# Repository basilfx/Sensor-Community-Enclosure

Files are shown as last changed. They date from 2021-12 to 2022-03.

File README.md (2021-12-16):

# Sensor Community Enclosure
3D printed version of a Sensor.Community Air Sensor enclosure.

## Introduction
This repository contains the parts and assembly instructions for creating my
version of the [Sensor.Community](https://sensor.community/en/sensors/airrohr/)
Air Sensor. This sensor uses a relativly cheap PM2.5/PM10 sensor, to measure
the air quality. This data is then shared with
[Sensor.Community](https://maps.sensor.community/) and other instances, to
keep track of the (local) air quality.

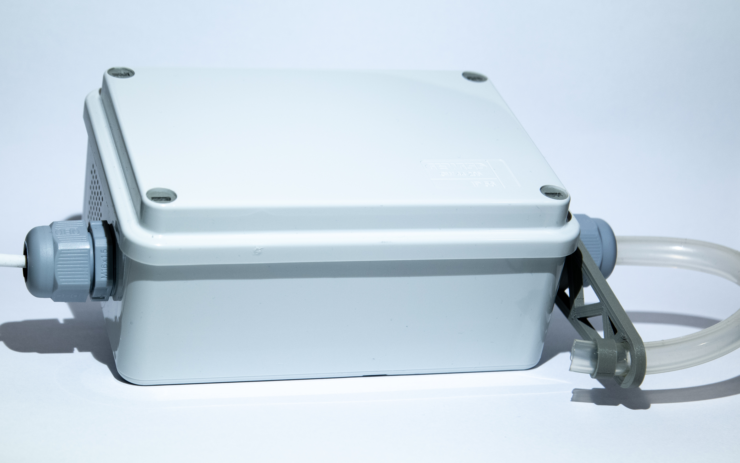
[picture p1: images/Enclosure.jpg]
Sensor enclosure overview.
[](images/Enclosure.jpg)
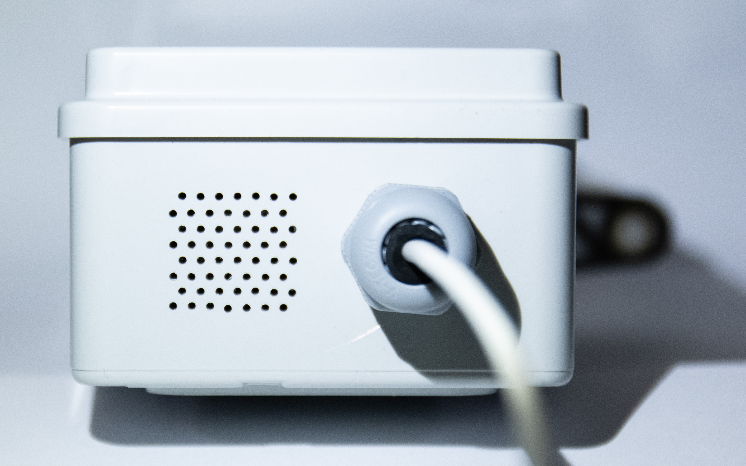
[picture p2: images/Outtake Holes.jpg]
Sensor outtake holes.
[](images/Outtake%20Holes.jpg)
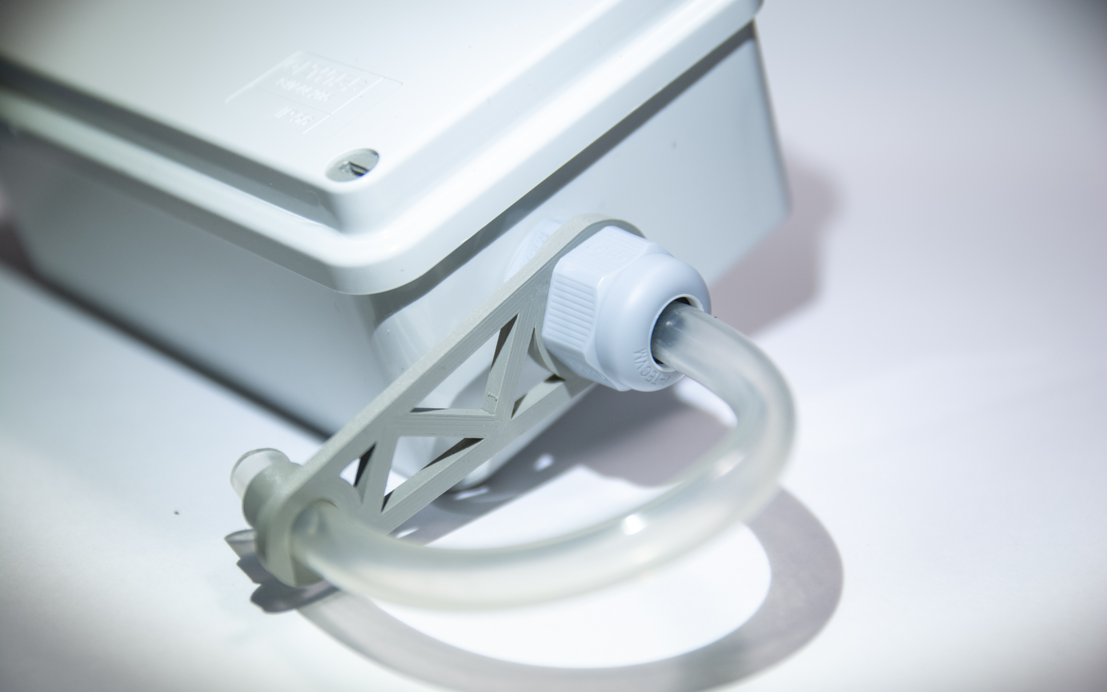
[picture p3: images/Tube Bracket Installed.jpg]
Sensor intake bracket.
[](images/Tube%Bracked%Installed.jpg)
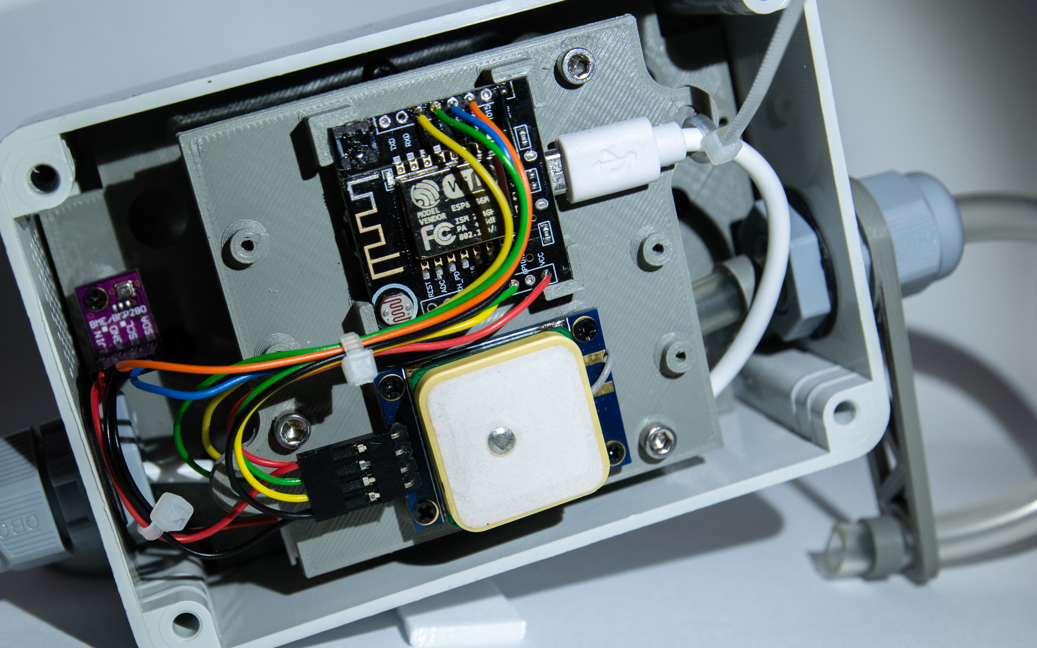
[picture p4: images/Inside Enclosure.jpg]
Inside the sensor.
[](images/Inside%20Enclosure.jpg)

## Features
* 3D printed parts (for the specific enclosure I used, +/- 80x120 mm)
* Rigid mounting with additional weatherproofing
* Air quality, temperature and GPS (location and altitude)

## Contents
* The `3d/` folder contains a 3D-printable designs for the necessary parts.
* The `firmware/` folder contains a compiled version of the Airrohr firmware I
  used (added for archiving reasons).
* The `images/` folder contains several pictures of the assembled sensor.

## Instructions
Printing, assembly and flashing instructions can be found in
[Instructions.md](Instructions.md).

## License
The work in this repository is covered by CC BY-NC-SA 4.0. See the `LICENSE.md`
file for more information.

Some parts of this project are covered by a different license.

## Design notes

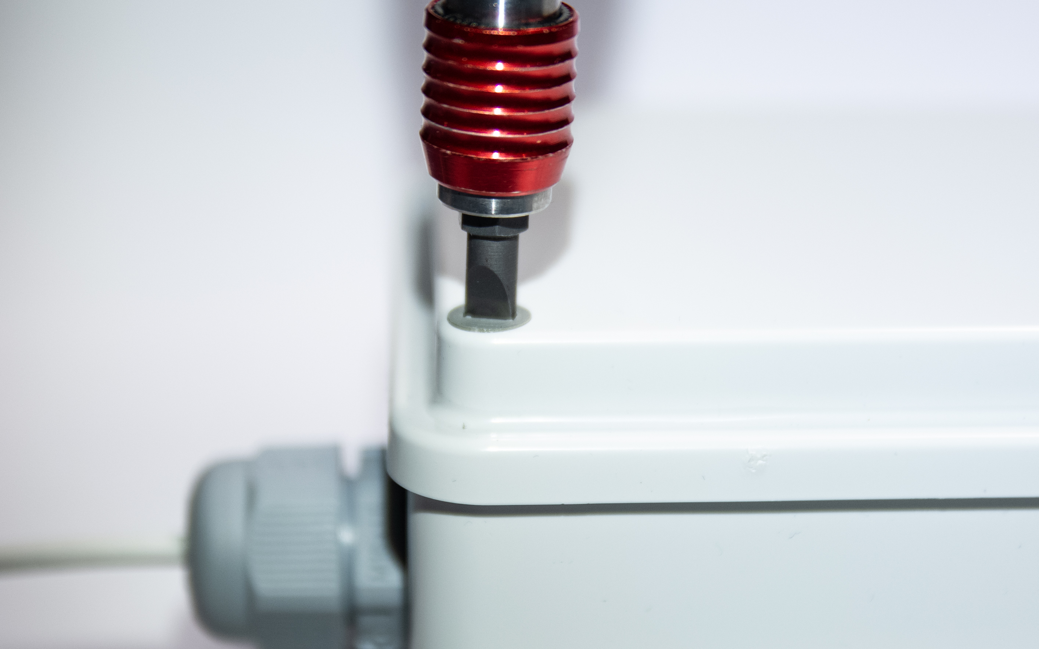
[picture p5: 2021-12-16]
images/Opening enclosure.jpg

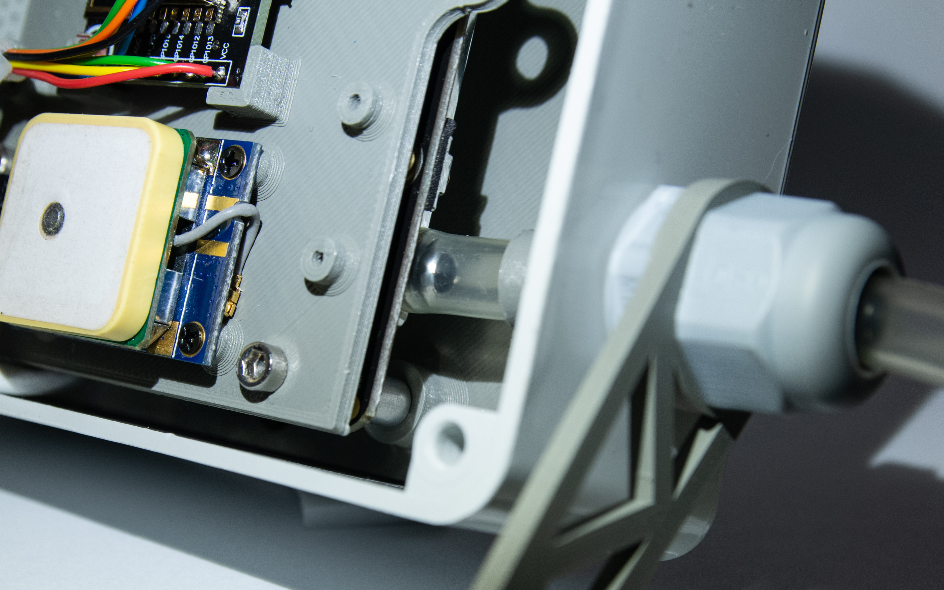
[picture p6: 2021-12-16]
images/Intake.jpg

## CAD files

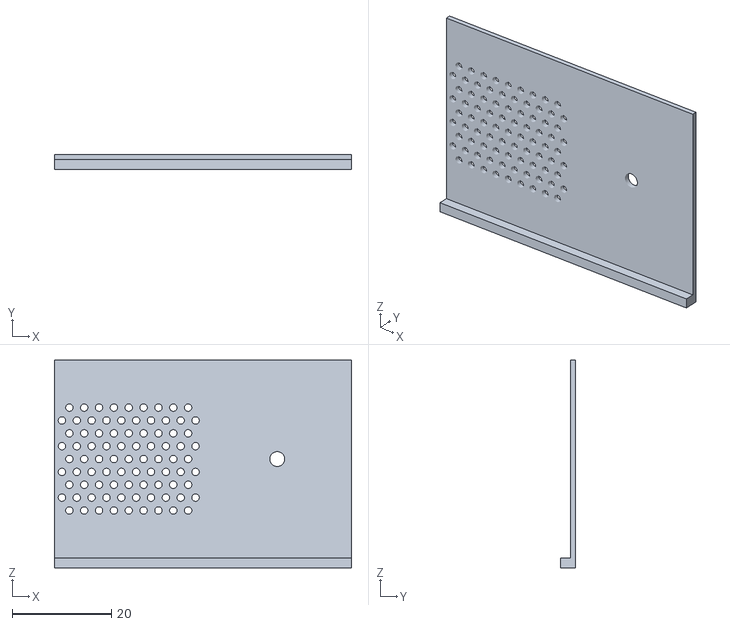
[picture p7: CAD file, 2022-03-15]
3d/enclosure/Drill Template - Bottom.stl
60.0 x 3.00 x 42.0

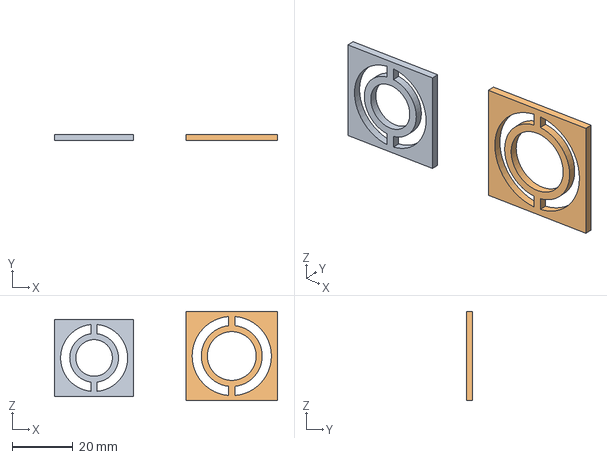
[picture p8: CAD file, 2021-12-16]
3d/other/Rubber Seal Template.step
73.2 x 2.00 x 29.4 mm

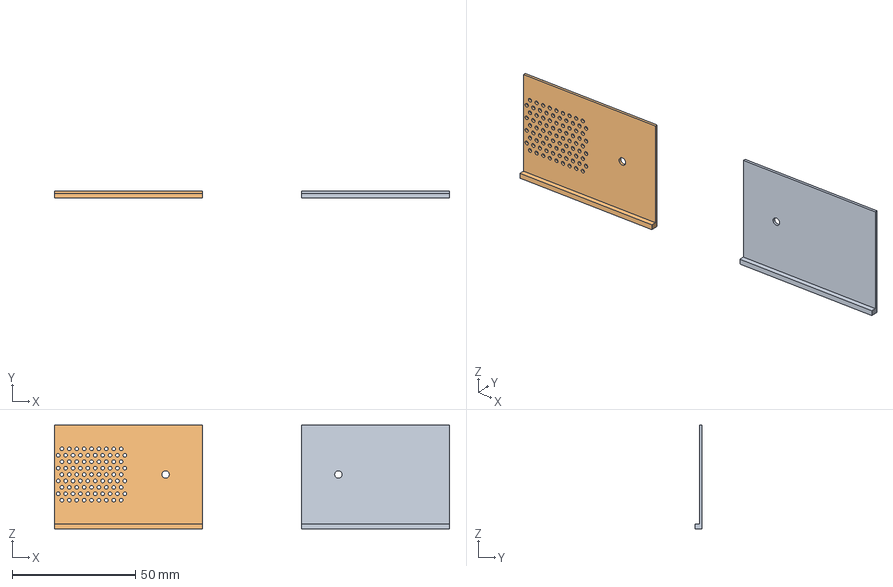
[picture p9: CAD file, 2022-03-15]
3d/enclosure/Drill Template.step
160.0 x 3.00 x 42.0 mm

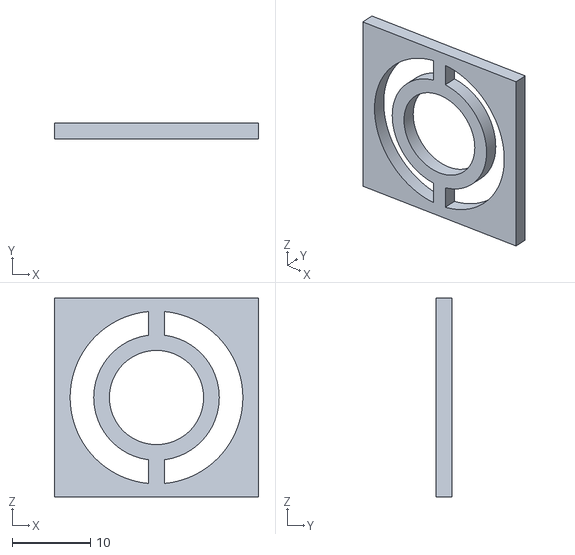
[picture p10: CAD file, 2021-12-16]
3d/other/Rubber Seal Template - 12mm.stl
26.0 x 2.00 x 25.3

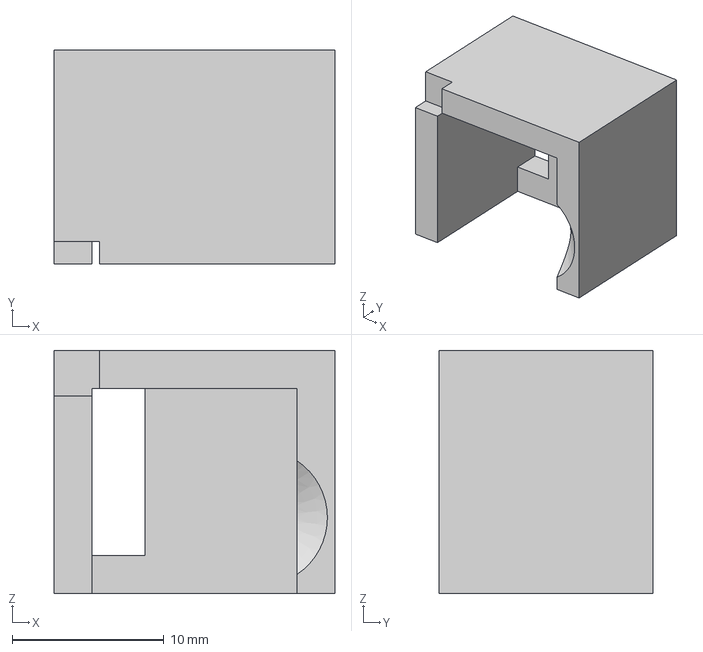
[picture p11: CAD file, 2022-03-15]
3d/enclosure/Temperature Sensor Cover.step
18.5 x 14.1 x 16.0 mm

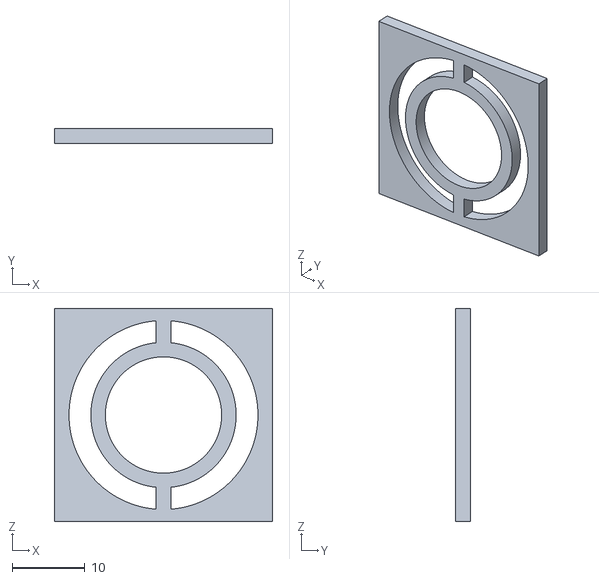
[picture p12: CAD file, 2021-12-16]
3d/other/Rubber Seal Template - 16mm.stl
30.0 x 2.00 x 29.4

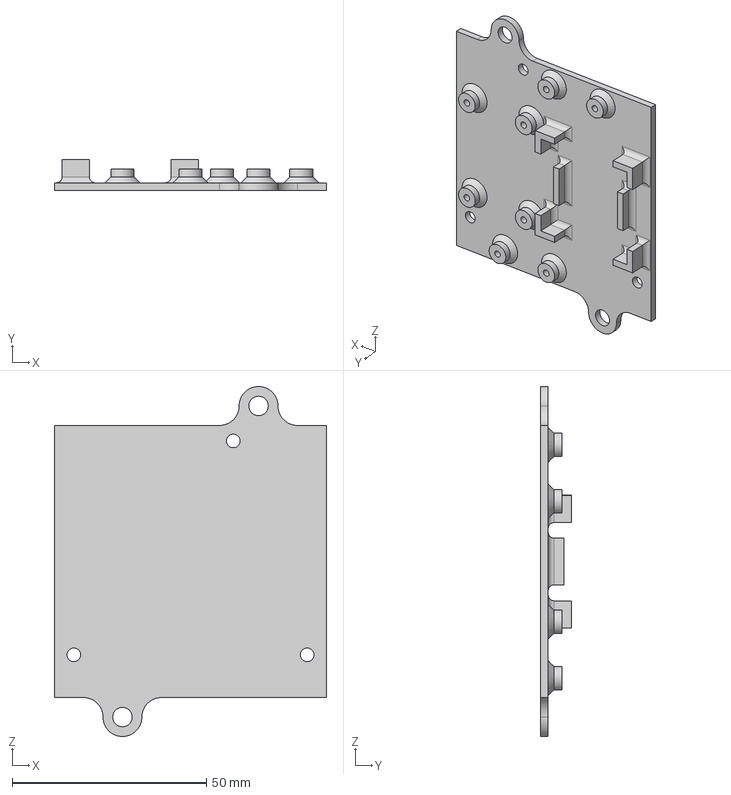
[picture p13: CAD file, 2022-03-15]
3d/enclosure/PCB Bracket - Witty Board.step
70.0 x 8.00 x 90.0 mm

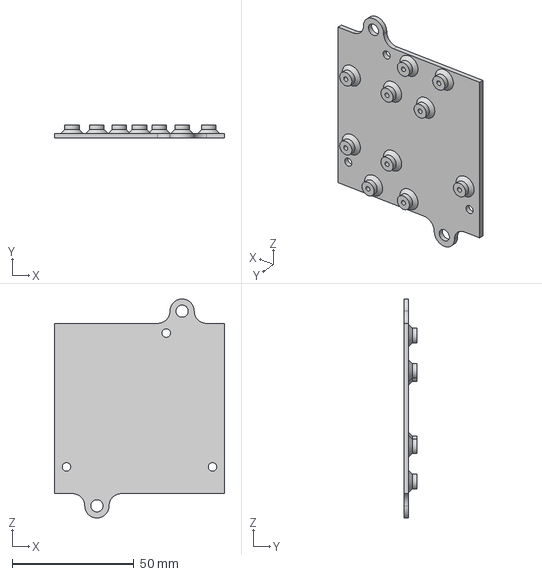
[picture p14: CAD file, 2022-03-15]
3d/enclosure/PCB bracket - Wemos D1 Mini V3.step
70.0 x 5.50 x 90.0 mm

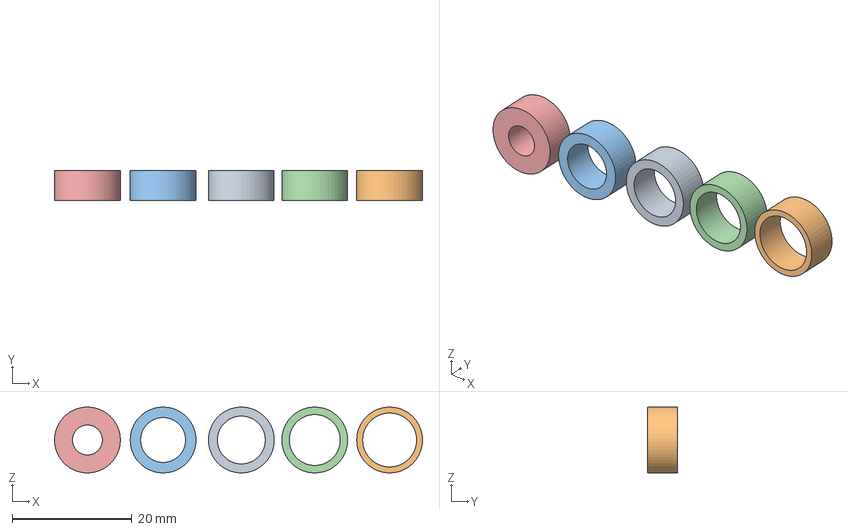
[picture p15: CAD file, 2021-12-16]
3d/enclosure/Tube Rings.step
61.4 x 5.00 x 11.0 mm

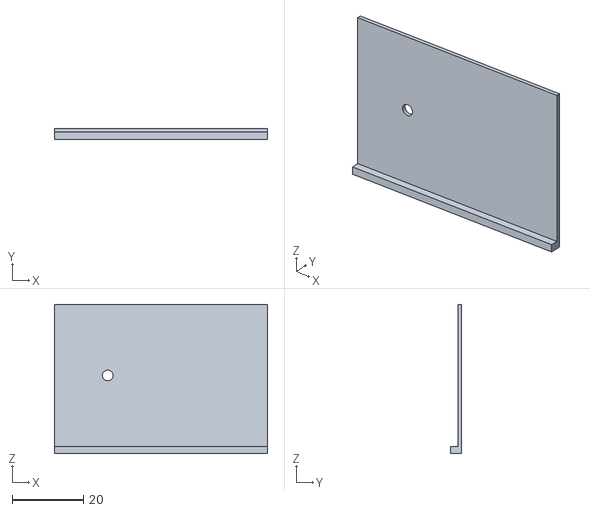
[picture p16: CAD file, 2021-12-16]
3d/enclosure/Drill Template - Top.stl
60.0 x 3.00 x 42.0

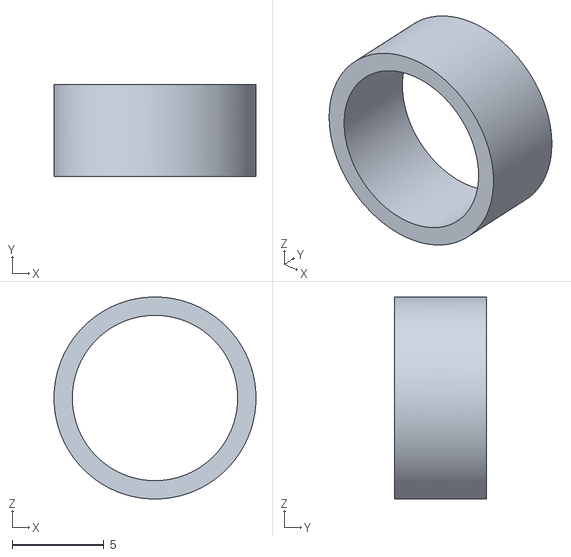
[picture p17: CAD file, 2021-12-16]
3d/enclosure/Tube Ring - 8mm.stl
11.0 x 5.00 x 11.0

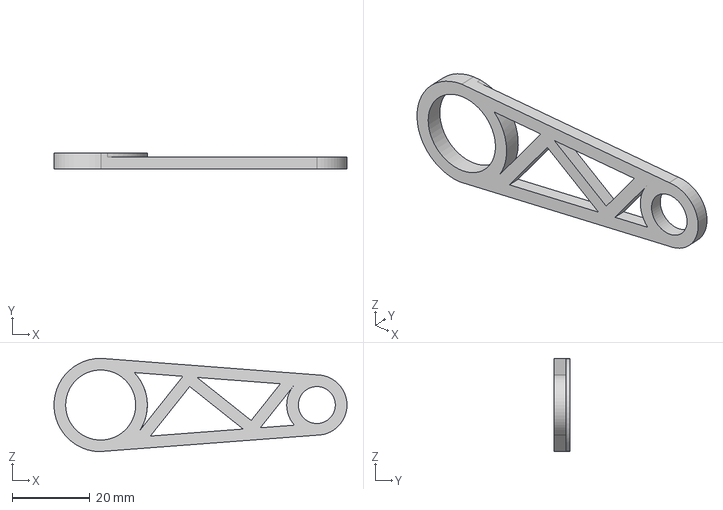
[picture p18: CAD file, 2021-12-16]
3d/enclosure/Tube Bracket.step
75.3 x 4.00 x 24.0 mm

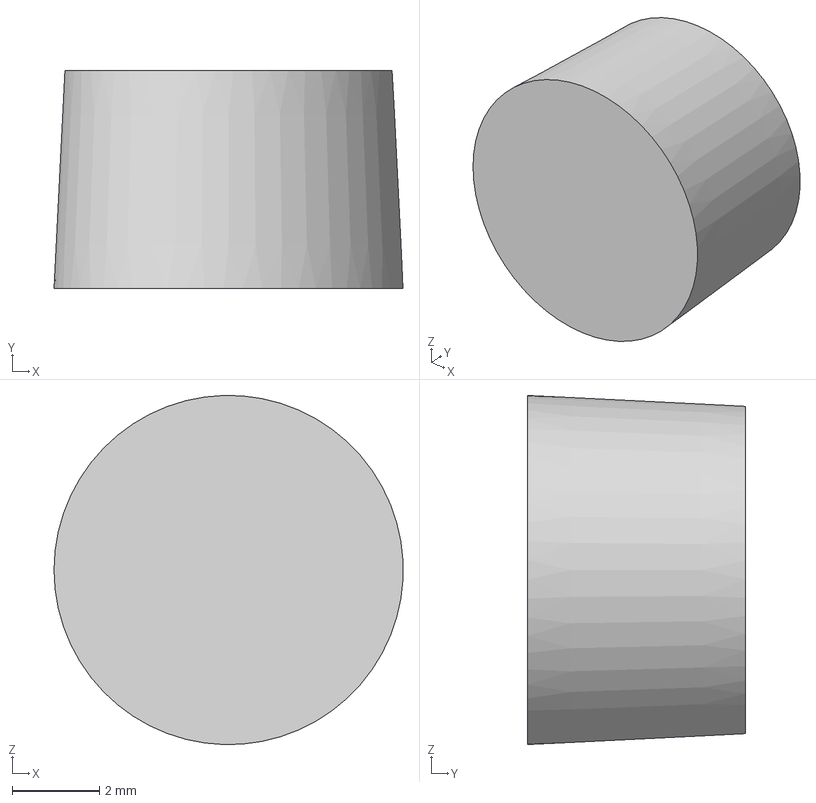
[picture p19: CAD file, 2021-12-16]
3d/enclosure/Screw Hole Cover.step
7.99 x 5.00 x 8.00 mm

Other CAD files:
3d/enclosure/Enclosure Bracket.step
3d/enclosure/Enclosure Bracket.stl
3d/enclosure/PCB bracket - Wemos D1 Mini V3.stl
3d/enclosure/PCB bracket - Witty Board.stl
3d/enclosure/Screw Hole Cover.stl
3d/enclosure/Temperature Sensor Cover.stl
3d/enclosure/Tube Bracket.stl

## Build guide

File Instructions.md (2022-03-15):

# Instructions

* [Introduction](#introduction)
* [Printing the parts](#printing-the-parts)
* [Assembly](#assembly)
  + [Creating the cable loom](#creating-the-cable-loom)
  + [Drilling the enclosure holes](#drilling-the-enclosure-holes)
  + [Installing the enclosure bracket](#installing-the-enclosure-bracket)
  + [Installing the cable glands](#installing-the-cable-glands)
  + [Installing the electronics](#installing-the-electronics)
  + [Hooking it up](#hooking-it-up)
    - [Flexible tube length](#flexible-tube-length)
  + [Finishing steps](#finishing-steps)
* [Flashing the firmware](#flashing-the-firmware)
* [Configuration](#configuration)
  + [Advanced configuration](#advanced-configuration)
    - [Temperature correction](#temperature-correction)
    - [GPS configuration](#gps-configuration)
* [Registration](#registration)
* [Home Assistant integration](#home-assistant-integration)
  + [Local Luftdaten](#local-luftdaten)
* [Mounting instructions](#mounting-instructions)
* [Troubleshooting](#troubleshooting)

## Introduction
The steps in these introductions are all the steps I needed to create a single
enclosure. Feel free to adapt, replace or skip any of the steps, to make your
own version.

Some of the photos in this guide are from a prototype version using the
Witty Board. While this might look different, all of the steps are quite
similar.

## Printing the parts
You can find the printable files in the [3d](3d/) folder. The parts do not
require special attention. Make sure that you print the parts with the biggest
flat surface down. At least 20% infill will ensure they are rigid enough. I
used PLA, but since the sensor must not be installed in direct sunlight, I do
not expect any problems.

It depends on the use-case if you need all the parts.

You need at least:

* Enclosure bracket
* PCB bracket
* Screw hole covers
* Temperature sensor cover

For usage with a flexible tube:

* Tube bracket
* Tube fixing ring (2x)

For easy drilling of the enclosure:

* Drill templates (top and bottom)
* Rubber seal templates (16 mm and/or 12 mm)

You might need to adapt the tube fixing rings to your particular tube. There
might be slight differences in the flexible tube outer diameter. The rings must
fit tightly, so they stay in place.

## Assembly

### Creating the cable loom

For this step, you will need:

* 4-pin 2.54 mm male header
* 4-pin 2.54 mm male header right angled
* 4-pin 2.54 mm female Dupont headers (2x) with terminal pins (8x)
* JST terminal pins (4x)
* Wires (thin, six colors if possible)
* Pliers, crimping tools and wire strippers

Optionally, if you plan to connect to the power line directly:

* 2-pin 2.54 mm female Dupont header with terminal pins (2x)
* 2-pin 2.54 mm male Dupont header with terminal pins (2x, for contra cable)

The sensors can be soldered to the ESP8266, but another option is to create a
cable loom and use wire-to-board connectors.

The cable should be assembled as follows (do not solder it to the ESP8266 yet):

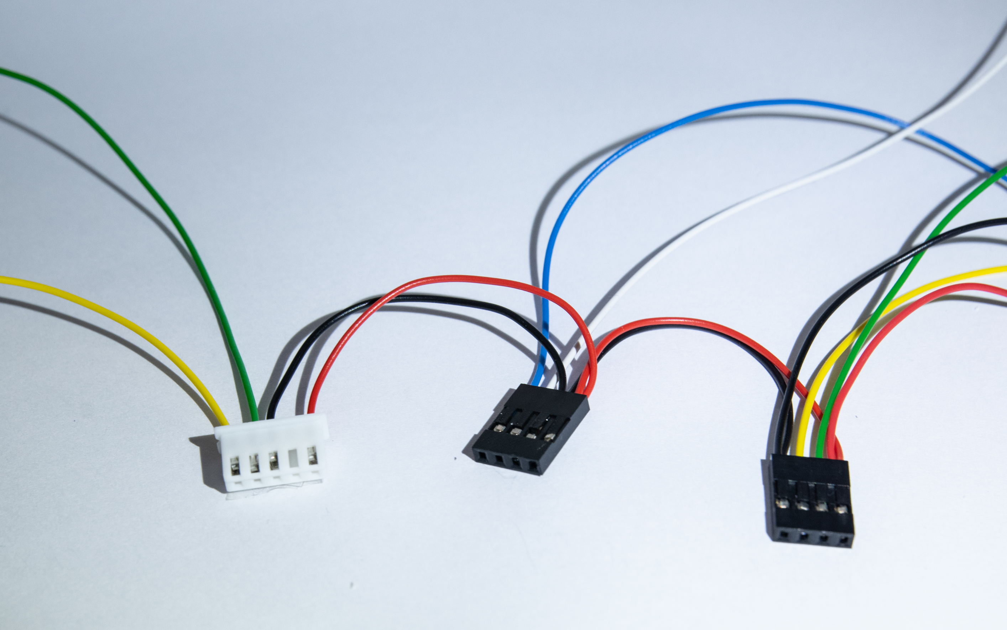
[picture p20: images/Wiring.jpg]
The actual wiring loom.
[](images/Wiring.jpg)
[Overview of the wiring loom.](images/Wiring%20Overview.svg)

You can re-use the JST connector housing that comes with the SDS011 cable.

### Drilling the enclosure holes
For this step, you will need:

* Enclosure (Gewiss GW44 205)
* A slow (hand-operated) drill with a 1 - 1.4 mm drill bit
* An electric drill with a 3 mm drill bit
* A 16 mm spade drill bit
* Small piece of scrap wood
* Strong adhesive tape
* Sharp chisel or another deburring tool

The drilling step is a time-consuming step.

Secure the drill templates on the top and bottom side of the enclosure, using
some strong adhesive tape. The templates should be centered and tightly mounted
to the edge of the enclosure.

The small holes should be drilled carefully. Use a hand-operated drill, because
an electric drill will melt the plastic, clogging up the drill and potentially
breaking the drill itself.

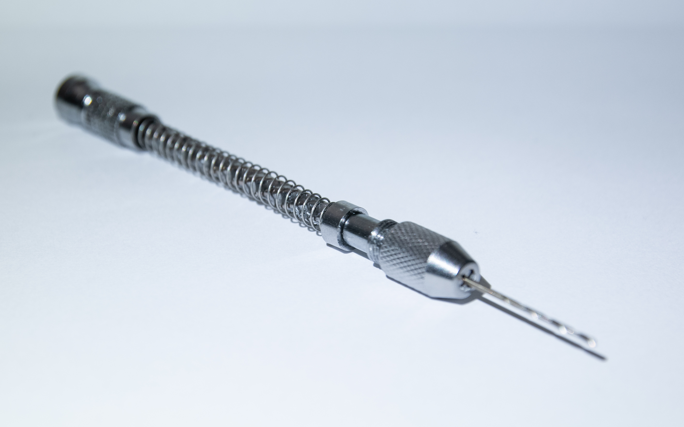
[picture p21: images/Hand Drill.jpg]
A hand drill
[](images/Hand%20Drill.jpg)
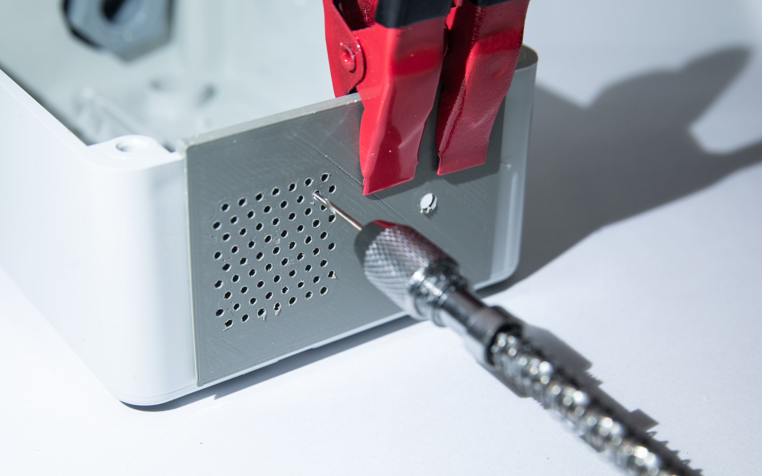
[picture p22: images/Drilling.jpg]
Drilling in of the outtake holes.
[](images/Drilling.jpg)

The bigger holes should be pre-drilled using a 3 mm drill bit first. Use a
piece of scrap wood on the back side, so that the drill bit does not shoot
through the plastic, potentially damaging the enclosure.

On the bottom side (next to the outtake holes), use the 16 mm spade drill bit
to create a hole for the cable gland for the power supply. On the top side, use
a 16 mm spade drill bit for the flexible tube as well. Use the piece of scrap
wood on the back side of the plastic.

**Note:** make sure that you hold the enclosure firmly during drilling. If the
spade drill bit gets stuck, it might start to rotate the enclosure.

**Note:** if you plan to directly solder the power supply cable, you can better
drill a 12 mm hole on the bottom side.

Clean-up all the holes and remove any of the burrs. This ensures that the
rubber seals can be mounted properly. A chisel works great in this case,
without scratching the plastic.

### Installing the enclosure bracket
For this step, you will need:

* Enclosure bracket
* M3 Brass inserts (5.3 mm outer diameter, 5 mm or 6 mm tall)
* M3 8 mm self-tapping button-head screws (4x)
* An electric drill with a 3 - 4 mm drill bit
* Small piece of scrap wood
* Soldering iron

Drill the enclosure mounting holes first, depending on your desires. If you
decide to hang it on two scows, make sure that you drill the two top holes
only. Use the scrap piece of wood to ensure that the drill bit does not shoot
through the case.

Insert the M3 brass inserts in the three bigger stand-offs on the enclosure
bracket. The easiest is to do this with a soldering iron. Make sure that the
molten plastic does not get inside the brass insert. One way to do so, is to
insert a small M3 bolt first (e.g. 5 mm or 6 mm bolt). If you struggle to get
the M3 brass inserts flush due to the molten plastic, you can decide to drill
the holes first, so that the molten plastic can get out.

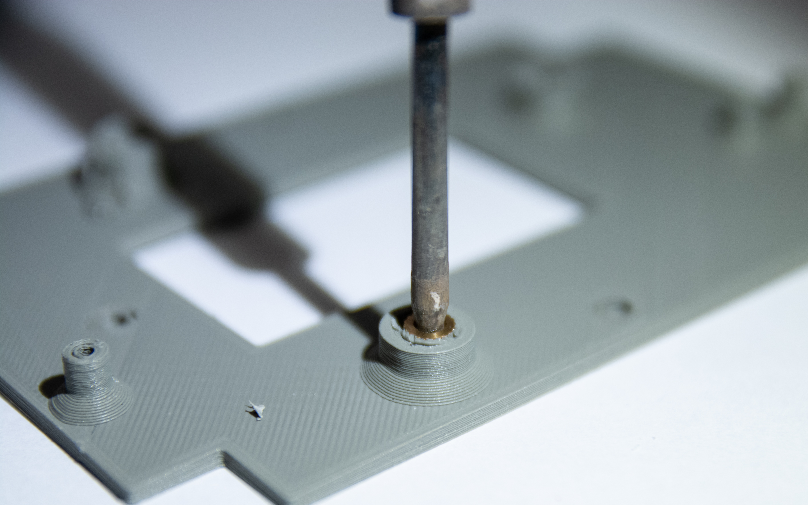
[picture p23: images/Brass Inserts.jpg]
Sensor outtake holes.
[](images/Brass%20Inserts.jpg)

Mount the enclosure bracket next. Use the four M3 self-tapping screws to secure
it to the enclosure.

### Installing the cable glands
For this step, you will need:

* Cable gland 16 mm (2x) including nut (2x)
* Rubber seal 16 mm (2x)

**Note:** you can also cut some seals from an old bicycle tire, using the
rubber steal template.

Install the cable glands on the top and bottom side. From the inside, put on
the rubber seal first and then the nut. Tighten the nut by hand, ensuring that
it is as tight as possible. Verify that it will not come loose when you tighten
the cable gland itself.

The rubber seal ensures that the cable gland does not get loose and prevents
water from coming in.

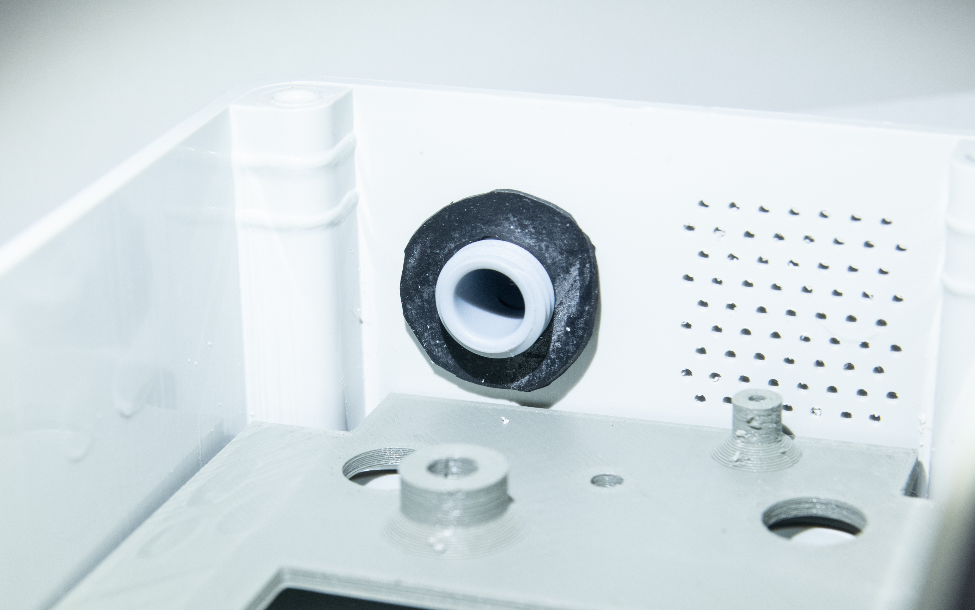
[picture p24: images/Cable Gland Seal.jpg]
Cable gland with seal.
[](images/Cable%20Gland%20Seal.jpg)
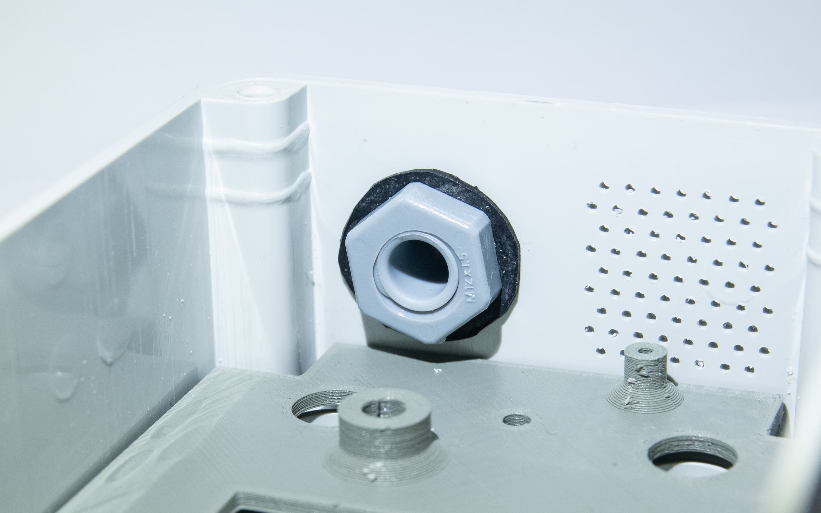
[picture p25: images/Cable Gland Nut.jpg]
Cable gland with seal and nut.
[](images/Cable%20Gland%20Nut.jpg)

If you decide to mount the enclosure, now is the time to mount it to its final
destination. The enclosure mounting screws will be hard to reach once you
finish the next step. To improve water resistance, use a M3 or M4 seal on the
inside between the screw and the enclosure.

### Installing the electronics
For this step, you will need:

* M3 15 mm brass stand-offs with 6 mm thread (3x)
* M3 spacer 3 mm (3x)
* M3 10 mm bolt
* ESP8266 (Wemos D1 Mini V3)
* Air quality sensor (SDS011)
* GPS sensor (NEO-6M, NEO-7M or NEO-M8N with the blue PCB and solderable
  antenna).
* Temperature and humidity sensor (BME-280, 5 V version)
* PCB bracket
* M2 self-taping screws
* Wiring loom, or wires for soldering
* Temperature sensor cover
* Hot glue

Fix the GPS sensor and the ESP8266 on the PCB bracket.

Install the brass stand-offs in the brass inserts in the enclosure bracket.
Then place the air quality sensor on top, with the fan down. Then place the
PCB bracket on top, using 3 mm spacers. Fix them with the 10 mm M3 bolts.

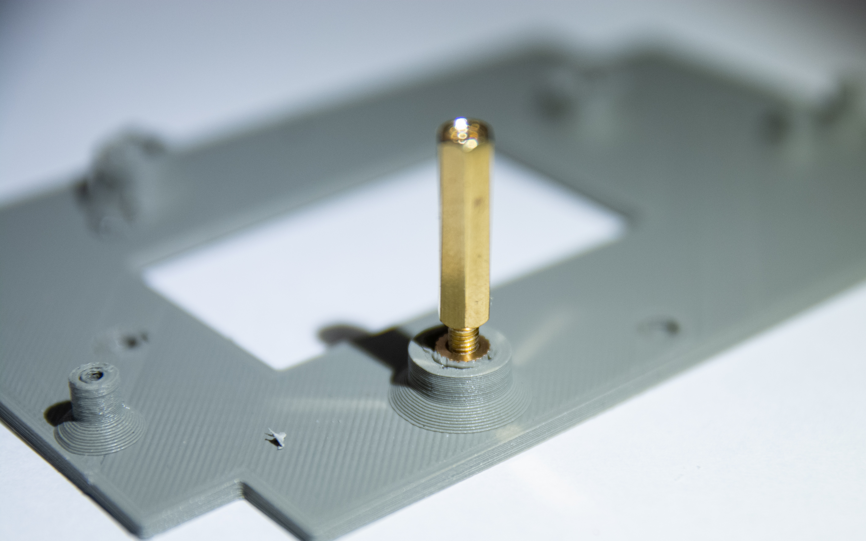
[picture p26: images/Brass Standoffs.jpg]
Installation of the brass standoffs.
[](images/Brass%20Standoffs.jpg)

The BME-280 temperature sensor can be mounted next to the outtake holes, using
a small screw. It is recommended to mount the temperature sensor cover as well,
to isolate the temperature sensor better from the inside air. A drop of hot
glue should keep it in place. I must admit that this sensor cover is an
afterthought, to make the temperature readings more accurate.

Finally, connect the wiring loom in accordance with the wiring diagram above.
Use the following pinout:

SDS011:

* Pin 1 (TX) -> Pin D1 (GPIO5)
* Pin 2 (RX) -> Pin D2 (GPIO4)
* Pin 3 (GND) -> GND
* Pin 4 (2.5m) -> unused
* Pin 5 (5 V) -> 5 V
* Pin 6 (1m) -> unused

BME-280 (5 V version):

* Pin 1 (VCC) -> 5 V
* Pin 2 (GND) -> GND
* Pin 3 (SCL) -> Pin D4 (GPIO2)
* Pin 4 (SDA) -> Pin D3 (GPIO0)

NEO-6M, NEO-7M or NEO-M8N:

* Pin 1 (VCC) -> 5 V
* Pin 2 (TX) -> Pin D5 (RX)
* Pin 3 (RX) -> Pin D6 (TX)
* Pin 4 (GND) -> GND

[Inside an assembled enclosure.](images/Inside%20Enclosure.jpg)

### Hooking it up
For this step, you will need:

* Tube fixing ring (2x)
* Tube bracket
* 15-20 cm flexible tube (6 mm inner diameter, 8 mm outer diameter)
* Power supply cable (e.g. USB cable)
* Zip tie

Insert the flexible tube through the cable gland and connect it to the intake
of the air sensor. Install a tube fixing ring on the inside. This ring should
prevent water (if any at all) from running down the tube into the sensor.
Then install the tube bracket on the cable gland and install the flexible tube
to the bracket, with a tube fixing ring on the end.

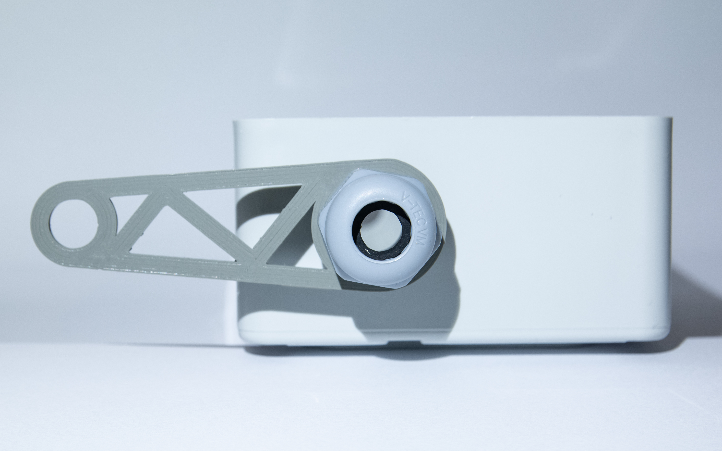
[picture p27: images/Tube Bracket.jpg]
Tube bracket without tube.
[](images/Tube%20Bracket.jpg)
[Tube bracket installed.](images/Tube%20Bracket%Installed.jpg)

Install the power supply cable. The USB cable should fit thourgh the 16 mm
cable gland. Route it behind the PCB bracket and connect it to the ESP8266. Use
zip tie to fix it to the PCB bracket top hole, for additional stress
relief.

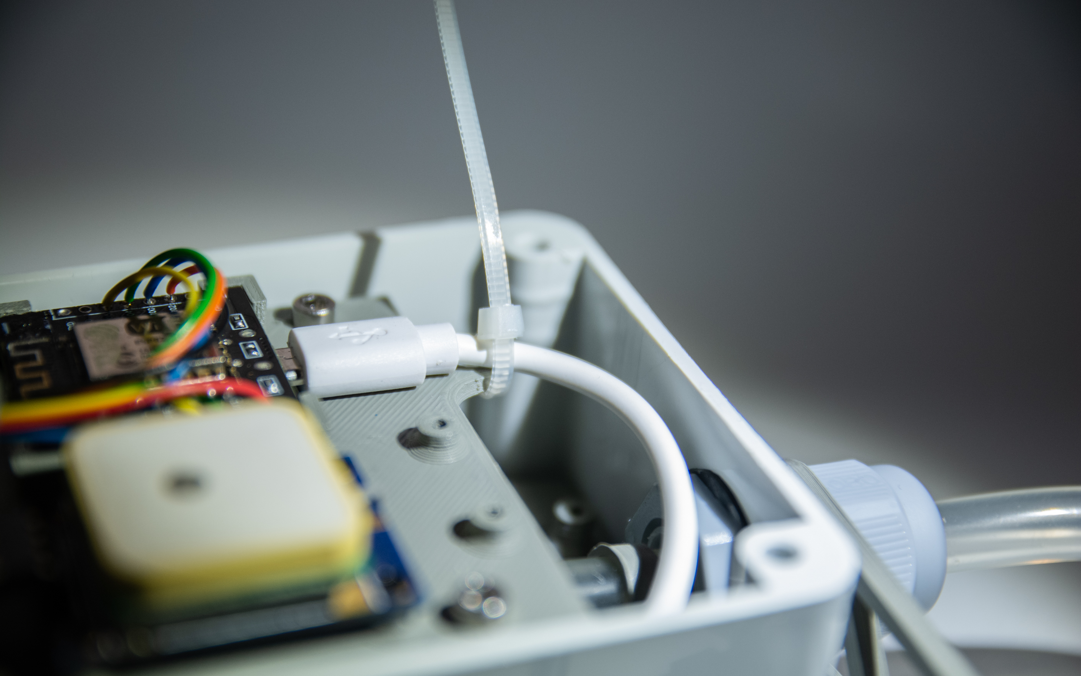
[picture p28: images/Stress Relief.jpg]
Zip tie for stress relief.
[](images/Stress%20Relief.jpg)

The cable gland on the bottom should be tightened all the way for the power
supply cable. This acts as an additional strain relief. The cable gland one on
top should be tightened as well, but not too tight. The flexible tube must not
be compressed too much otherwise it could obstruct the air flow. Make sure that
if you pull on the tube, it cannot move. Then look down the tube, to see if you
do not see any inward affliction of the tube.

#### Flexible tube length
The shorter the tube, the better it is. According to the datasheet of the
sensor, a tube length up to 1 m is allowed. The original manual suggests the
use of a 20 cm tube. The Dutch National Institute for Public Health and the
Environment, who are [stimulating] people to join the Sensor.Community,
suggests to use a tube less than 5 cm, to increase plausibility of
measurements.

For my design, a tube of approximately 15-20 cm is necessary to create an
unobstructed 180 degree bend. Without a tube, it would be hard to ensure that
the sensor is mounted upright AND make it water-resistant. It also ensures that
the sensor sucks up fresh air (away from the outtake). You can decrease the
tube length if you mount the sensor on a dry location (even removing the tube
bracket at all).

The tube has a inner diameter of 6 mm (~28 mm² of area), the actual intake
port has a diameter of 5 mm (~19 mm² of area). The 85 outtake holes (~96 mm²
of area) should allow for an unobstructed air flow. I have compared my sensor
with other nearby sensors, and it performs identical.

A more-scientific study observed a decrease in the maximum air flow of the
flexible tube, with longer tube lengths. Comparing 20 cm with 100 cm, the air
flow decreased linearly from 664 ml/min to 412 ml/min. Every 1 cm of tube would
impact the maximum air flow by about 0.5 %. Note that this is the maximum air
flow, which may be much higher than the air flow generated by the air quality
sensor. More details of this research can be found
[here](https://pudi.lubw.de/detailseite/-/publication/90536).

### Finishing steps
For this step, you will need:

* The screw hole covers (4x)
* M3 x 7 mm rubber seals (4x)

Last step is to install the lid. The enclosure comes with four screws to close
the lid. For additional water proofing, add a M3 rubber seal and finish it off
with a screw hole cover.

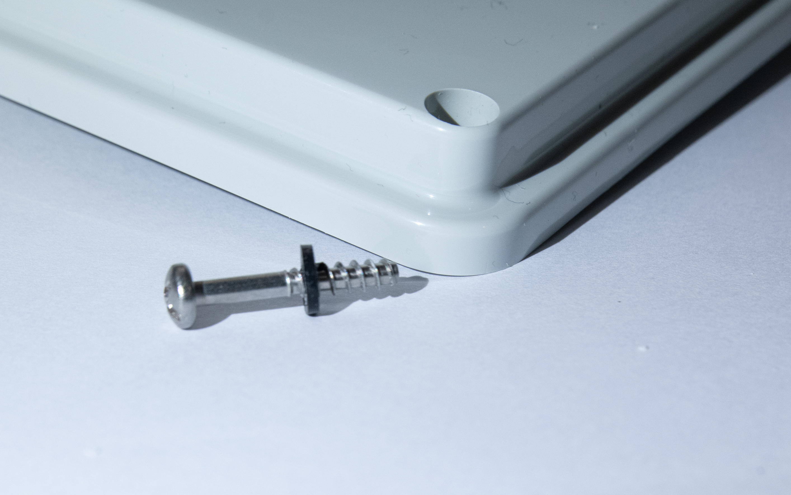
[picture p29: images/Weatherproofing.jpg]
Weatherproofing of the screws.
[](images/Weatherproofing.jpg)

The screw hole cover can be removed with a large flat head.

Your sensor is now ready for use.

## Flashing the firmware
For this step, you will need:

* A micro USB cable
* [esptool.py](https://github.com/espressif/esptool)
* Firmware file (see [firmware](firmware/) folder.

From the command line, invoke:

```
esptool.py --port [PORT] write_flash -fm dio 0x00000 latest_en.bin
```

Replace `[PORT]` with the serial port of your sensor. It is typically
`/dev/tty/tty.USBxyz` on Linux and `COMn` on Windows.

Once flashing is completed, power cycle the sensor.

## Configuration
Power-on the sensor. If it has not been configured before, it will start a
wireless network. Connect to this network, and navigate to http://192.168.4.1.

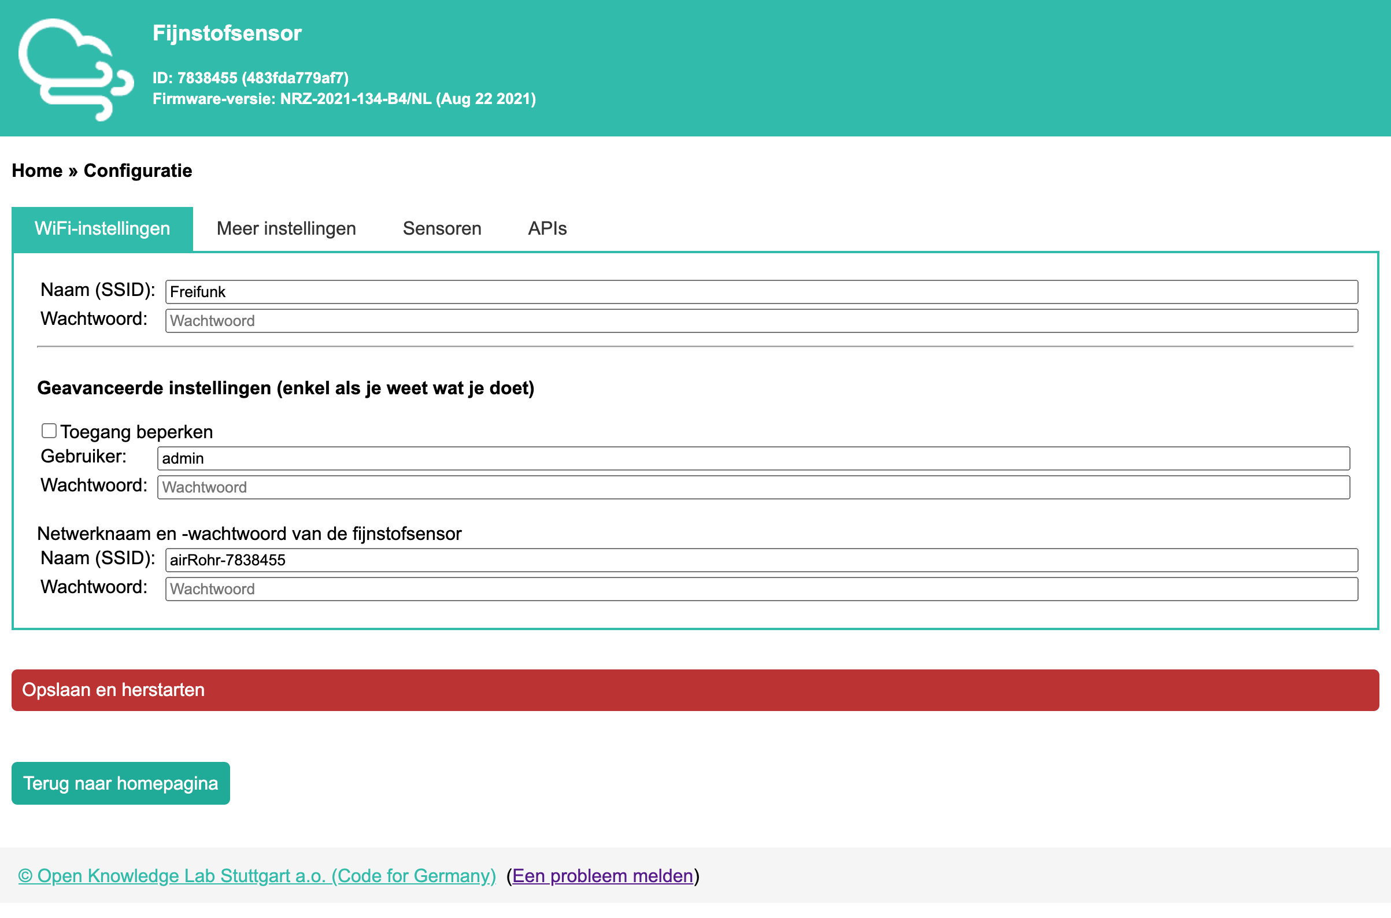
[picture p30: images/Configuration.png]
Configuration screen (Dutch firmware).
[](images/Configuration.png)

On the configuration page, you can configure the WiFi network to use. It is
also possible to configure the hardware and API connections. Some points of
attention:

* Make a note of the 7-digit identifier shown in the top bar. You will need
  this in the next step.
* Enable beta updates. Note that your sensor may seem unresponsive the next
  time it boots, because it will most likely download the new firmware.
* Enable the Sensor.Community API integration (using HTTPS). Enable others as
  desired. You do not need to enable any API integrations if you decide to use
  the local Home Assistant integration.
* Ensure that you enable the right hardware. For this build, enable
  * SDS011
  * BME280
  * GPS (NEO-6M, NEO-7M or NEO-M8N)

If the sensor cannot find the configured wireless network, it will start its
own wireless network again. You can then start over.

### Advanced configuration
The WiFi chip and the GPS chip are power-hungry. This results in some
heating-up of the enclosure, depending on the exact module used and the amount
of WiFi traffic. This will affect the BME280 temperature and humidity readings.

#### Temperature correction
It is possible to account for an offset of the temperature readings in the
firmware (this is not possible for humidity, unfortunately). To find the
offset, it is possible to run the sensor for some time, without the lid of the
enclosure mounted. The graphs below show the offsets for two of my sensors
(yellow line is the one without the lid mounted).

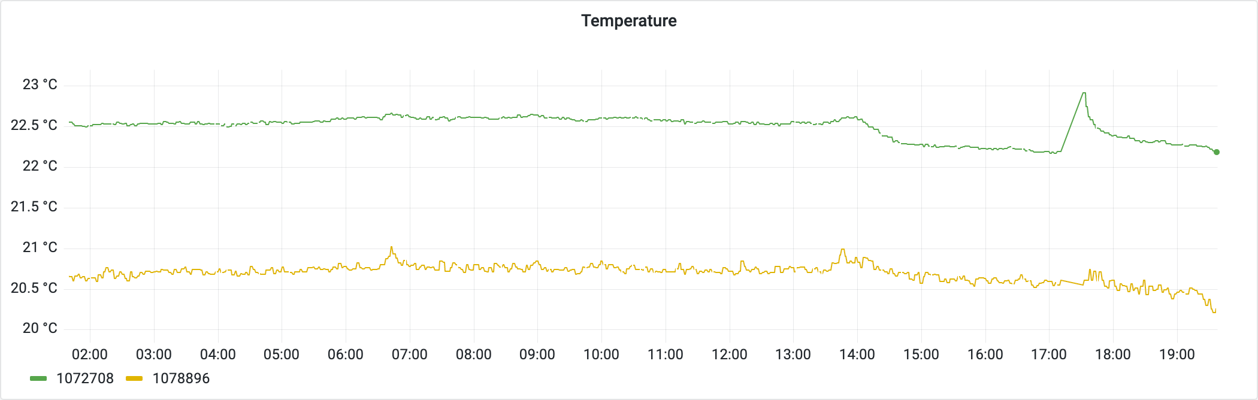
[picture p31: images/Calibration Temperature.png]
Temperature offset with and without lid.
[](images/Calibration%20Temperature.png)
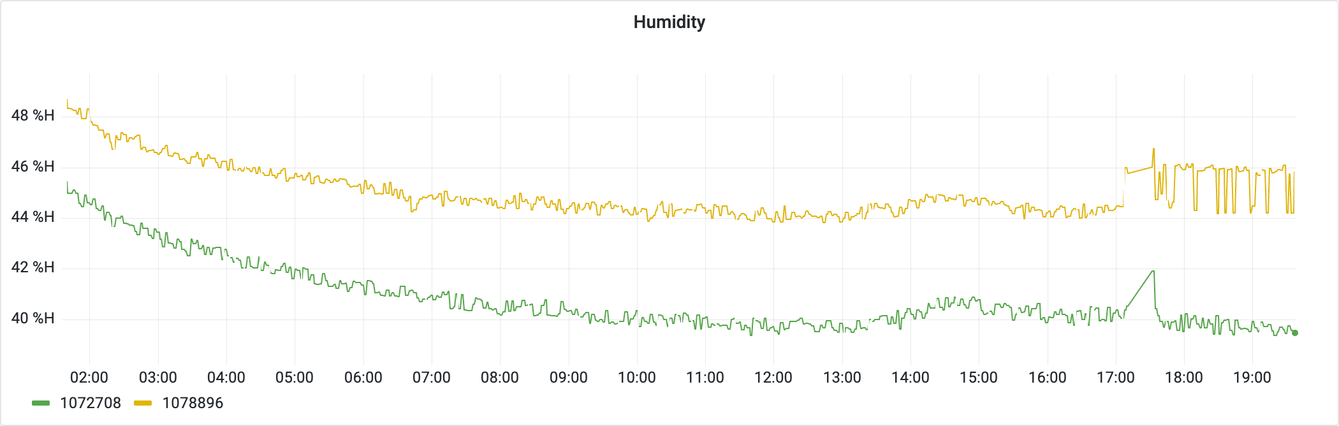
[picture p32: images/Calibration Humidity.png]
Humidity offset with and without lid.
[](images/Calibration%20Humidity.png)

The graph show an offset of about 1 °C to 2 °C, and it follows the temperature
curve of the enclosure without the lid. Similar results were achieved in
different environments.

#### GPS configuration
The NEO-M8N is more-efficient than the NEO-6M or NEO-7M. Using the u-blox
configuration tool, it is possible to enable more-efficient power saving modes,
at the expense of accuracy (which isn't a problem for a stationary device). Do
note that that not all devices have built-in flash for storing configuration
parameters, so they might be erased after power cycling. Consult the following
sources for more information:

* https://www.u-blox.com/sites/default/files/products/documents/u6-PowerMgt_AppNote_%28GPS.G6-X-10014%29.pdf
* https://www.u-blox.com/sites/default/files/products/documents/PowerManagement_AppNote_%28UBX-13005162%29.pdf

## Registration
If you decide to contribute to Sensor.Community, you can go to
https://devices.sensor.community/ to create an account.

Once you have created an account, you can add sensors using the sensor
identifier from the previous step. An important note here is that you cannot
modify an existing sensor, and if you delete it, you cannot register it again.
Make sure that you add three sensors under the 'Hardware Configuration'
section:

* SDS011
* BME280
* GPS-NEO-6M (also for NEO-7M or NEO-M8)

Once your sensor is registered, you can look it up at
https://maps.sensor.community/. It might take some time before the first
measurements appear.

If you made any mistakes during the registration, please check
[this](https://forum.sensor.community/t/reregister-unregister-sensor/494) for
details on how to get support (you will need to send an email and ask them to
manually correct the registration).

## Home Assistant integration
There are two sensor for Home Assistant available. The first one uses the
Sensor.Community API, the other directly talks with the sensor.

* https://www.home-assistant.io/integrations/luftdaten/
* https://github.com/lichtteil/local_luftdaten

### Local Luftdaten
After installing the integration per installation instructions, add the
configuration below to your `configuration.yaml`. Aadapt the IP address to
match your sensor's IP address. The scan interval should not be less than 120
seconds, because the sensor itself does not update faster than that.

```yaml
sensor:
  - platform: local_luftdaten
    host: [IP HERE]
    scan_interval: 120
    name: Air Quality Sensor
    monitored_conditions:
      - BME280_humidity
      - BME280_pressure
      - BME280_temperature
      - SDS_P1
      - SDS_P2
```

Restart Home Assistant, and you should have additional sensors to add to your
dashboard.

## Mounting instructions
There are some mounting instructions:

* Mount the sensor upright (tube on top). The sensor requires this position, so
  that gravity optimizes the flow of particles through the air sensor. It also
  ensures that water cannot enter the outtake holes on the bottom.
* Make sure that splashing water cannot enter the outtake holes on the bottom.
* The sensor should be mounted in the outside and average environment. This
  means that you should not place it next to a chimney, for example.
* Ideally, the sensor should be mounted at 1.5 m height. During the
  registration of the sensor, you can account for other heights.
* Do not mount the sensor in direct sunlight. The temperature sensor might
  report incorrect measurements.

Finally:

* Inspect the sensor once or twice per year. Check if it is still mounted
  securely, that there is no dirt inside the sensor and the tube is clean.
* Discoloration due to UV light is to be expected.

## Troubleshooting
Some things to consider when troubleshooting a sensor:

* If you plug in the power, you should hear the fan spin up for a brief
  period. If it does not turn on, check the connections. If it does not turn
  off, something might be wrong with the firmware.
* Check the web interface for debug logging and error counters.
* Some ESP8266 boards have on-board USB-to-serial. The firmware will output
  logging to this port (at 9600 baud).

[stimulating]: https://www.samenmetenaanluchtkwaliteit.nl/data/plausibiliteit-van-fijnstofmeting

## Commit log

2021-12-16 Initial commit of instructions.
    [Drill Template - Bottom.stl, Drill Template - Top.stl, Drill Template.step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]
2021-12-16 Add photos of assembly and final product.
2022-01-04 Elaborate on the tube length implications.
2022-01-04 Improve sensor configuration and registration.
2022-01-04 Calibrate the temperature offset.
2022-03-15 Increased diameter of spacers
    This should result in more rigid spacers that do not snap off too
    easily.
    [PCB bracket - Wemos D1 Mini V3.step, PCB bracket - Wemos D1 Mini V3.stl]
2022-03-15 Add PCB bracket for Witty Board
    [PCB Bracket - Witty Board.step, PCB bracket - Witty Board.stl]
2022-03-15 Add temperature sensor cover
    [Temperature Sensor Cover.step, Temperature Sensor Cover.stl]
2022-03-15 Update wiring to include external power input
2022-03-15 Update bottom drill template
    Add more holes for more airflow
    [Drill Template - Bottom.stl, Drill Template.step]
2022-03-15 Improved instructions
    - Document different GPS models
    - Added temperature sensor cover
    - Textual improvements
